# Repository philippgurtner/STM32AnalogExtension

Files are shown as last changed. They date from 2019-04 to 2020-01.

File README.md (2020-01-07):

# STM32AnalogExtension
In diesem Repository befinden sich die Daten für eine analog Erweiterung, bestehend aus einem externen ADC für das STM32F0-Discovery Board. 
Im weiteren ist die komplette Dokumentation, so dass die Projektschritte verstanden werden können und auch das Projekt verständlich wird. 

Das Projekt ist OpenSource & darf frei verwendet (und so auch gerne verbessert) werden. 
Ich hoffe viel Freude damit zu bereiten. 
:)

# Projektdokumentation

## Aufgabe
Für die Bereichsübergreifende Projekte der Schule sollte eine Erweiterung für das STM32F051Discovery Kit erstellt werden. 
Dieses Projekt ist eine Analoge Erweiterung mit einem 24Bit 4kSps externen ADC. Dabei ist wichtig dass die Erweiterung mit SPI Angesteuert wird. 
Mehr im Fokus des Projektes stand die Einfachheit, so das das Produkt einfach angewendet werden kann, als es Sehr genau ist. 
So wurde bei der Temperaturmessung auf die Konstantstromquelle Verzichtet, jedoch können zukünftige Anwender die tolle Auflösung mit allen Problemen und Hürden selbst erfahren. 

### Vorgaben
-	Es soll nur eine Seite für Anschlüsse genutzt werden
-	Die Erweiterungsplatine sitzt also zur rechten oder linken Seite des STM32F0-Board
-	Die Seite wird durch die Versorgungsspannung vorgegeben, wenn möglich 3V
-	Platinendicke 1,6mm
-	Lagenanzahl: 2
-	Bestückungsdruck: Schriftgrösse 1mm  Name der Bauteile, Stecker Pin 1, Signalnamen Stecker 
    - 2mm Name Projekt, Datum, Namen der Ersteller
-	Line Space ≥200μm
-	GND-Plane
-	Abmessung Discovery-Board: 33Pin Header

### Zielsetzung
- Das Board muss passend als Erweiterung für das Devboard sein, so dass es einfach adaptiert werden kann. 
- Die Hauptanwendung besteht darin einen 3-Leiter PT100 zu messen.
- Weiter soll möglich sein, durch eine Buchse eine eigene Messspannung hinzuzuführen, so dass auch diese digitalisiert werden kann. 
- Durch einen hochauflösenden ADC (>16Bit) werden dann hohe Genauigkeiten möglich.

## Grundlagen
### Analog-Digital-Converter (ADC)
Die Aufgabe eines ADC’s, ist die Umwandlung von analogen Signalen zu digitalen Daten. Dabei sind mehrere Faktoren wichtig, wie SampleRate und Auflösung (Bittiefe). Um die Signale zu ermitteln müssen wir wissen, was für eine Auflösung der ADC hat. Denn mit diesem, wissen wir wie fein wir das analoge Signal aufteilen können und so die digitalen Werte erhalten. Anhand der SampleRate sehen wir, wie viel Mal der ADC in der Sekunde das analoge Signal maximal abtasten kann. Mit diesen beiden Werten können wir dann in der Software die Werte in unser Signal umrechnen.
### Temperatursensorschaltungen

Um einen Temperatursensor anzuschliessen gibt es verschiedene Möglichkeiten. Diese sind für thermisch abhängige Widerstände, welche als Temperatursensoren funktionieren. Zum Beispiel PT100 oder PT1000. 

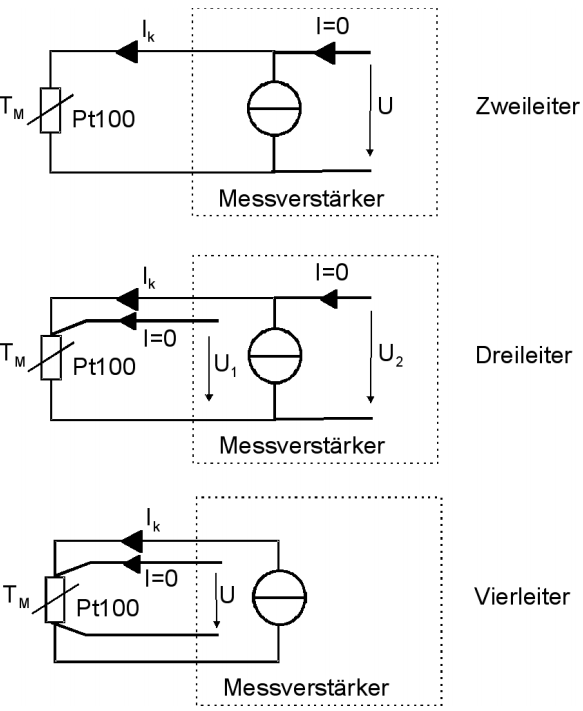
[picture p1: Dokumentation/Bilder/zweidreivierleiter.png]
Schaltung Zweileiter, Dreileiter, Vierleiter


#### Zweileiter-Messung
Der Messwiderstand (Temperatursensor) wird über dieselbe Leitung gespiesen wie auch die Temperatur gemessen wird. Daher, dass über die Leitungen ebenfalls etwas Spannung abfällt, wird dieser Fehler nicht mit einberechnet und wird zu einem Messfehler. 
#### Dreileiter- Messung
Bei der Dreileitermessung wird der Messwiderstand über eine zusätzliche Leitung mit Strom versorgt. Daher fällt einerseits der Messfehler der Spannung weg, da die Temperatur über eine unbelastete Leitung gemessen werden kann. Da der Strom I=0A auf der Messleitung ist kann auf der gemeinsamen Leitung der Messfehler herausgerechnet werden -> Siehe Anwendung. 
#### Vierleiter- Messung
Bei einer Vierleitermessung werden der Messstrom und die Messspannung je auf einer separaten Leitung geführt. So kann der Widerstand komplett ohne Spannungsabfall auf der Messleitung gemessen werden.

## Evaluation
###	ADC
Beim Evaluieren eines ADC’s gibt es sehr viele Möglichkeiten. Die wichtigsten Eigenschaften sind Auflösung (Bittiefe) und Geschwindigkeit (Samples per Second). 
Für dieses Projekt spielt die Geschwindigkeit keine grosse Rolle, da Prozesswerte abgefragt werden möchten und es sich nicht um eine Digitalisierung eines hochfrequenten Signals handelt. 
Die Auflösung spielt für dieses Projekt die grössere Rolle. Da gezeigt werden möchte wie genau der ADC ist, soll die Temperatur des Temperatursensors ohne jegliche Verstärkung gemessen werden. 
Die Berechnungen zu der Temperaturauflösung sind in Tabelle 1 zu finden. \todo

### Temperatursensor
Als Temperatursensor eignet sich ein thermisch abhängiger Widerstand sehr gut. Diese werden oft auch in Industrieanlagen verwendet. Da gerade ein fertiger PT100 Sensor an Lager ist wird dieser Verwendet, er benötigt nur eine Buchse auf der Platine um den Sensor anzuhängen. 
###	Weitere Anschlüsse
Als zusätzliche Anschlüsse wurden BNC Buchsen ausgewählt. Durch ihre Standardisierung und häufigen gebrauch eignen sie sich gut um weitere Signale anzulegen und zu messen. 
Es können dann entweder Oszilloskop-Messspitzen oder auch Adapter auf andere Hochfrequenz Stecker, wie auch auf Bananenbuchse verwendet werden. 

## Schaltungsaufbau
### 3-Leitermessung
Für diese Schaltung wird eine Dreileiter-Messung für den Temperatursensor verwendet, da diese sehr einfach aufzubauen, wie auch dann interessant zu verarbeiten ist. Weiter sind hier nur 3 ADC Kanäle nötig obwohl wie bei einer 4-Leiter Messung auch der Widerstand der Messleitung herausgerechnet werden kann.  
### ADC-Serial Interface
Der ADC besitzt ein Serial Peripherie Interface (SPI). Über diese kann mit dem Microcontroller kommuniziert werden. Damit die Peripherie nicht per Bit-Banging angesteuert werden muss, müssen die SPI-Anschlüsse beim Microcontroller an einen SPI fähigen Port geroutet werden.
### Funktion der Schaltung / Überlegungen
Dank folgender Rechnung wird ersichtlich wie die Spannung über dem PT100 berechnet werden kann. Dies funktioniert nach der theoretischen Betrachtung in Abbildung 4.
Es werden hier alle anderen Spannungen herausgerechnet. 

## Auswertung V0.1 
### Hardware
Während der Lötarbeit konnten wir nichts Auffälliges erkennen, was beim Löten problematisch werden könnte. Erst beim Konfigurieren der SPI-Schnittstelle mit der STM32CubeMX-Software, haben wir festgestellt, dass die SPI-Schnittstelle nicht frei auf alle Pins mapbar ist, wie wir das fälschlicherweise aus dem Datenblatt gelesen haben.
Somit müssen am Schema noch einige Anpassungen gemacht werden. Weiter haben wir auch während der Bearbeitung gemerkt, dass der ADC mit Differenzmessung arbeitet. Dies bedeutet, er misst die Differenz zwischen zwei Kanälen. Möchte man eine Spannung absolut messen, so muss dies mit einer Differenzmessung zu Masse erfolgen. Der Chip bietet die Möglichkeit im INPMUX-Register als negative Referenz den AINCOM-Pin zu verwenden, der aber mit Masse verbunden sein sollte.
Für die ersten Versuche mit dem Prototyp haben wir die Kontakte auf der Leiterplatte korrigiert, so dass wir Tests durchführen konnten. Als Erweiterung für die nächste Version wäre zusätzlich eine Stiftleiste vorzusehen, dass die SPI-Analyse einfacher mit einem Logicanalyzer erfolgen kann. Dies hat auch einen Vorteil für den späteren Unterricht, so kann die SPI-Schnittstelle einfacher analysiert werden. 

In der nachfolgenden Tabelle sind die Leiterplattenänderungen festgehalten:

| WAS | von | Nach | div. |
|---|---|---|---|
| Clock | PA4 | PA5 | SPI |
| MOSI | PA5 | PA7 | SPI |
| CS | PA7 | PF5 | SPI |
| AINCOM | Nc | GND | Differenzmessung |
| Stiftleiste | | | Für Debugging / SPI-Analyse |
| Widerstände R12-R14 | Eingang von ADC | weglassen | Können Störungen auf Messleitung verursachen |
| BNC-Abschwächer | 2.2k Ohm | Spannungsteiler mit 47kOhm und 2.2kOhm | Somit können Eingangsspannungen bis zu 50V angelegt werden und nicht nur 2.5V über die Interne Referenz |
| 5.08mm schraubklemme | Weglassen | | So können die Temperatursignale direkter und präziser geroutet werden. Der Stecker wird nicht benötigt. |
| Kondensatoren 1uF | AIN0, AIN1, AIN2 | GND | Filterung der Temp Messung |
| Kondensator 1uF | AIN0 | AIN1 | Filterung der Temp Messung | | |

## Softwarerealisierung 
### Konfiguration mit STM32CubeMX
Vorzunehmende Konfigurationen in STM32CubeMX, um die SPI-Schnittstelle zu verwenden: 
Beim Starten das STM32F0-Discovery Board auswählen, so werden die Taster und LEDs richtig initialisiert
-   Pinout & Konfiguration:
    - Pin-Konfiguration
        - PF5: 	ADC_CS
        - PC4: 	ADC_START
        - PC5: 	ADC_RESET
        - PB0: 	ADC_DRDY
    - Modul Connectivity --> SPI1 hinzufügen
        - Data Size: 	8Bit
        - Prescaler:
        - First Bit: 	MSB First
        - Clock Polarity (CPOL): 	LOW
        - Clock Phase (CPHA): 		2 Edge
- Project Manger
    - Code Generator
    - Generate Files: Generate peripheral initialization as a pair... 
        (So wird nicht eine lange main.c-Datei erzeugt)

### Verwenden von HAL-Library 
Hardware Abstraction Librarys, kurz HAL, dienen dazu unabhängig von der verwendeten Hardware, eine Software zu schreiben. So kann eine mit HAL geschriebene Software einfach auf ein anderes System portiert werden und das System übernimmt die Hardwaresteuerung, so dass der Nutzercode nicht (gross) angepasst werden muss. So wird zum Beispiel das Schreiben eines Pins ganz einfach, man muss sich nicht mehr überlegen wo der gerade angeschlossen ist, man benutzt einfach das Userlabel zum Pin. 
```c
HAL_GPIO_WritePin(ADC_CS_GPIO_Port, ADC_CS_Pin,X)
// X=1 --> Ausgang wird auf 1 gesetzt
// X=0 --> Ausgang wird auf 0 gesetzt
```

### SPI-Analyse mit Logicanalyzer

Erweiterungen siehe Anhang
In vielen Fällen kann es hilfreich sein, wenn man mit einem Busprotokoll arbeitet, dieses auch zu messen. Es stand uns dazu ein PicoScope6 zur Verfügung. Sie können bis zu 16 Digitalanalysen und 2 Analoganalysen machen. Es ist ein Oszilloskop ohne Bildschirm. In der Software (Für Windows, MacOS und Linux) kann man das PicoScope steuern. Folgend unsere Erfahrungen. 
Im Anhang befindet sich eine Anleitung wie man eine Analyse der SPI Daten machen kann.

## Softwarefunktionen
Einen kurzen Einblick in die Funktionen welche eingesetzt werden. Weitere Details können dem Code entnommen werden. 
### Registermanipulation
Zum Schreiben und lesen von Registern gibt es die Funktionen (Auszug .h File): 

\todo

Wenn nur ein Register gelesen / geschrieben werden muss, so kann jeweils die ADCreg**** Funktion benutzt werden
### Commands
Der ADC kann über verschiedene Kommandos gesteuert werden. Diese sind alle in der "ADS1204S0x.h" Datei definiert.
```c
void ADCsendCommand(uint8_t op_code);
```
Der Funktion können die Verschiedenen op_codes mitgegeben werden. 

### Berechnungsfunktionen
#### ADC Werte auslesen
Um die Spannung über dem PT100 zu berechnen, werden alle Spannungen der drei ADC`s ausgelesen. Wie hier dargestellt messen die ADC`s folgende Spannungen:

```math
\mathrm{ADC0}=U_{\mathrm{Leiter}}+U_{\mathrm{PT100}}+U_{\mathrm{Leiter}}+U_{\mathrm{Mess}}\bigm\mathrm{ADC1}=U_{\mathrm{Leiter}}+U_{\mathrm{Mess}}\bigm\mathrm{ADC2}=U_{\mathrm{Mess}}\bigmU_{\mathrm{PT100}}=\mathrm{ADC0}-2\times U_{\mathrm{Leiter}}-U_{\mathrm{Mess}}\bigmU_{\mathrm{PT100}}=\mathrm{ADC0}-2\times\left(\mathrm{ADC1}-\mathrm{ADC2}\right)-\mathrm{ADC2\bigm}U_{\mathrm{PT100}}=\mathrm{ADC0}-2\times\mathrm{ADC1}+\mathrm{ADC2}
```
### Dimensionierungen und Berechnungen
Als Temperatursensor wird ein PT100 verwendet. Nach Spezifikation hat der Temperatursensor bei 0°C einen 100Ω Widerstand. Je nach Temperatur verändert sich der Widerstand, nach einer bestimmten Kurve. 
Als Messstrom wird bei 0°C 0.5mA verwendet. Da sich der Temperatursensor selbst erwärmt darf dieser Messstrom nicht zu hoch gewählt werden.
Um den geflossenen Strom durch den ADC zu messen, wird über einem präzisen Referenzwiderstand die Spannung gemessen, welche vom Messstrom erzeugt wird.

Anschlüsse:
Es wurde eine Temperaturmessung mittels PT100 3-Leiter Widerstand vorgenommen. 
Als zusätzliche Anschlüsse wurden BNC Buchsen ausgewählt. Durch ihre Stndrdisierung und often gebrauch eignen sie sich um weitere Signale anzulegen und zu messen. 

# Schaltungsaufbau
## ADC-Serial Interface
Der ADC besitzt ein Serial Peripherie Interface (SPI). Über dies kann mit dem Microntroller Komunizieren. 
Damit die Peripherie nicht per Bit-Banging angesteuert werden muss, müssen sie beim Microcontroller mit bei einem SPI fähigen Port verbunden werden.
# Dimensionierung
Als Temperatursensor wird ein TP100 verwendet. Nach Spezifikation hat der Temperatursensor bei 0°C 100R Widerstand. Je nach Temperaturänderung verändert sich der Widerstand nach einer Spezifizierten Kurve. 
Als Messstrom wird bei 0°C 0.5mA verwendet. Da sich der Temperatursensor selbst erwärmt darf dieser Messstrom nicht zu hoch gewählt werden. 

Um den Geflossenen Strom durch den ADC zu messen wird über einem Refererenzwiderstand die Spannung gemessen welche vom Messstrom erzeugt wird. 

# Einführung Picoscope

Das Picoscope ist ein Logicanalyser. Mit ihm ist es Möglich mehrere Digitale Signale zu Analysieren und die Daten auszuwerten. Um Herauszufinden ob die Serielle Kommunikation richtig Funktioniert kann man mit diesem Hilfsmittel einfacher messen und die Daten analysieren. 

## Vorbereitung

Um Das Picoscope an einem PC benutzen zu können sind einige Schritte notwendig. 

### Installieren der Software

Die Software kann auf der Webseite von Picosope unter > Downloads heruntergeladen werden. 
Hier muss die Genaue Modelbezeichung angegeben werden. (Wir verwendeten das Picoscope der Schule [*PicoScope 2206B MSO*](https://www.picotech.com/downloads/_lightbox/picoscope-6))

### Anschliessen der Digitalen Kanäle

Die Digitalen Kanäle befinden sich beim 16-Pin Stecker in der Mitte. Das Mitgelieferte Kabel dient um mit dem UC Board zu verbinden. 

### Einrichten der Software

1. Digitale Kanäle Gruppen

   1. Kanal Auswählen

   2. Kanal intelligent benennen

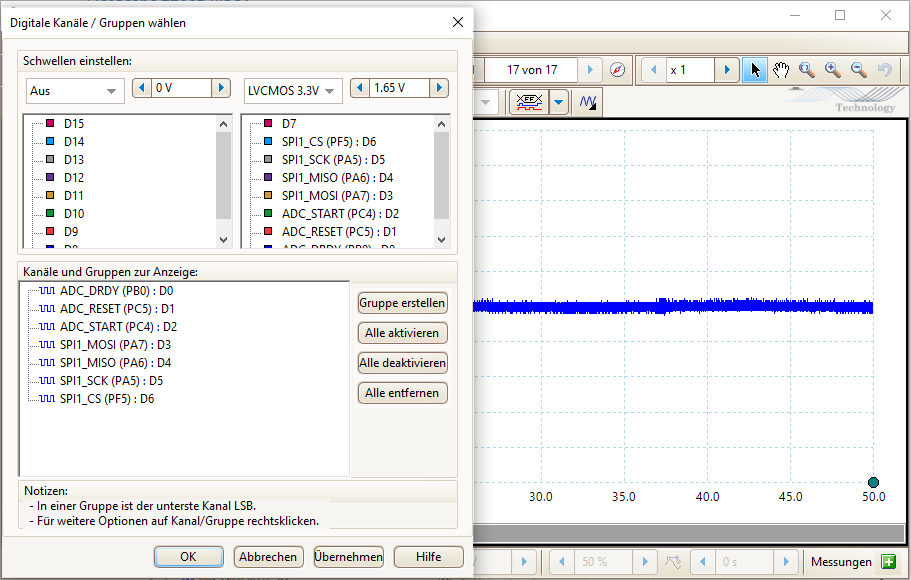
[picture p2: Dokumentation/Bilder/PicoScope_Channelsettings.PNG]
Digitale Kanäle
      

2. Hinzufügen eines Seriellen Encoders:

   1. Werkzeuge > Serielle Entschlüsselung -> Erstellen > SPI >

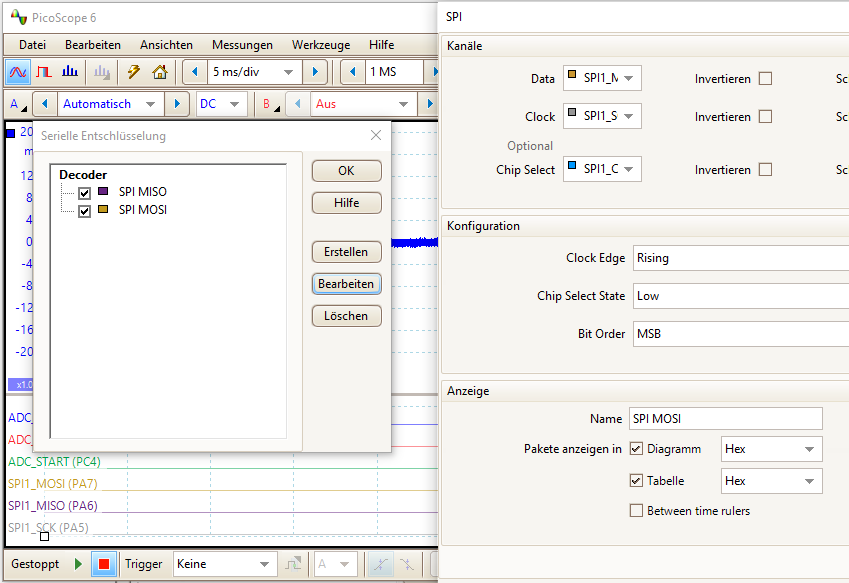
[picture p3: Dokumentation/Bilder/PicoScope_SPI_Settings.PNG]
SPI Analyser MISO and MOSI


3. Setzen des Triggers (In der untersten Leiste)
   1. Trigger: Einzeln
   2. In den Triggereinstellungen (Rechts vom Trigger) kann auf Digital > CS Pos Flanke gesetzt werden
   3. Start

## SPI Analyse

Mit den Empfangen Daten lässt sich verstehen was in SPI gesendet wird

Folgend im Code und Als Analyse:

MISO, Die Daten werden vom Master an den Slave gesendet. Die Rückgabe des Slaves ist nicht wichtig. 

```c
HAL_GPIO_WritePin(ADC_CS_GPIO_Port, ADC_CS_Pin,0);

uint8_t au8_txdata = {0x42,		// Register INPMUX_REG_ADDR (0x02) | Write command 0x40
                      0,		// Write length -1 = 0
                      0x3C};	// Data = ADS_P_AIN3 (0x30)+ ADS_N_AINCOM (0x0C)		
HAL_SPI_Transmit(&hspi1,au8_txdata,3,10);
HAL_GPIO_WritePin(ADC_CS_GPIO_Port, ADC_CS_Pin,1);
```

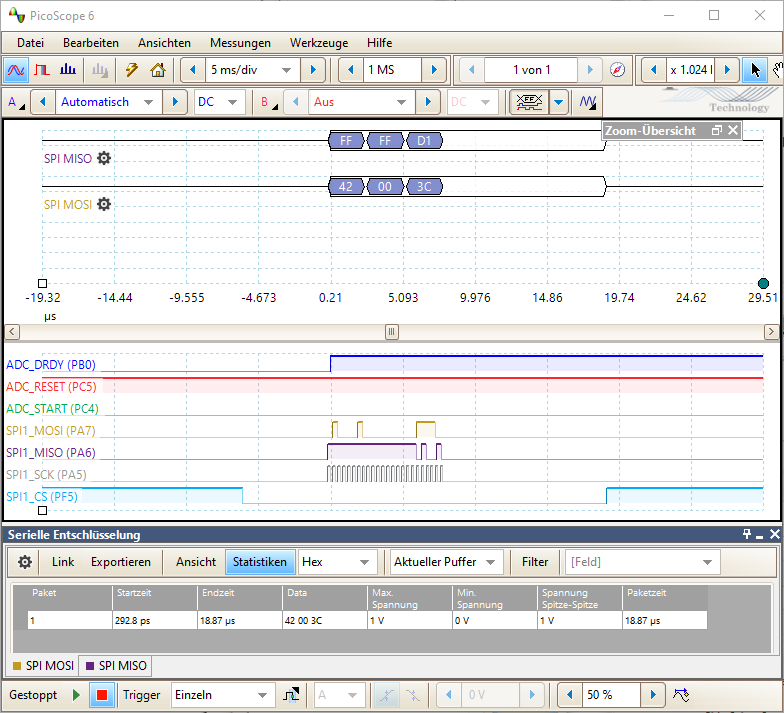
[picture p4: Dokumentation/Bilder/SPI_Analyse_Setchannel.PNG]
SPI Set Channel


# Variablen Viewer installieren (debuggen)

Das STMStudio ermöglicht es eine *debug Datei zu Importieren und diese Laufen zu lassen. So können mehrere globale Variablen angesehen werden. So kann eine Langzeitanalyse des Verhalten gemacht werden. 

- STM-STUDIO-STM32 (von https://www.st.com/en/development-tools/stm-studio-stm32.html ) installieren (benötigt Java https://www.java.com/de/download/win10.jsp)

- STM Studio öffnen

- "File" > "Import variables from executable" öffnen
  - "Executable file" .elf Datei suchen (im STM Projekt unter "Debugger")
  - (Warnung Ignorieren)
  - Variable zum Monitoren auswählen 
  - "Import" , "Close"

- Variable (Display Variables) in Viewer hineinziehen (Drag and Drop)

- Start Knopf drücken (Debugger aus IDE darf nicht gleichzeitig aktiv sein)

- Im Viewer: Rechtsklick, "Autorange" > "Both Axis"

- Eventuell als Balken darstellen, maximum wert beachten (über hex ganz einfach manuell einstellbar)

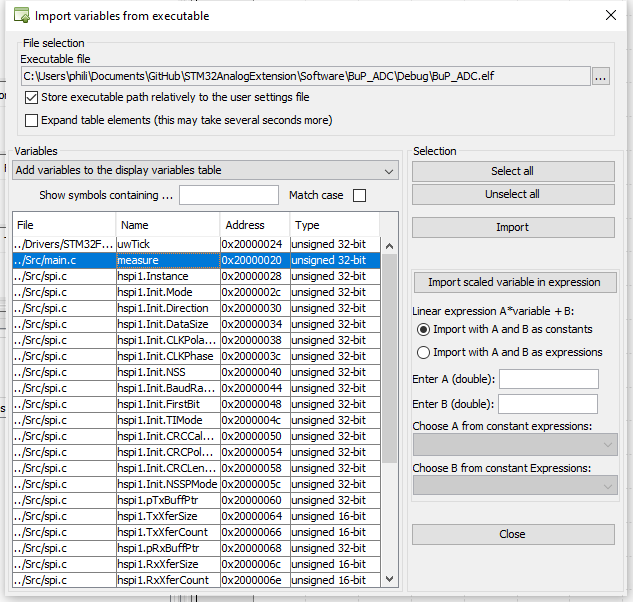
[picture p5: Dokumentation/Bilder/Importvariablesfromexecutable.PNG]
Import variables


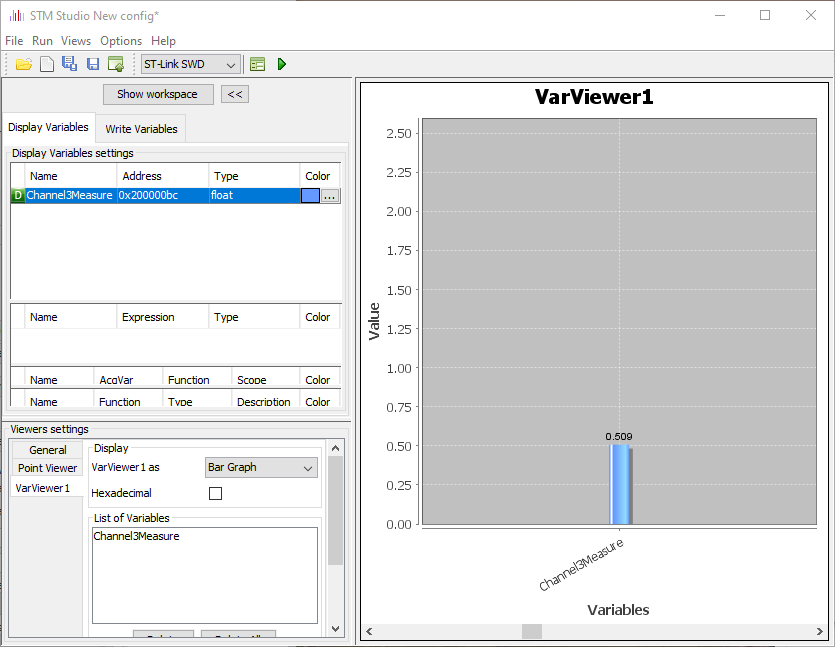
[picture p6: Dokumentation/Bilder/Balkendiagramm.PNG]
Variablenviewer als Balkenanzeige


# Sorry, die vollständige Dokumentation ist Leider nicht Opensource (und vorallem .docx), jedoch wird das Projekt bei Gelegenheit hier noch zu ende Dokumentiert (natürlich in MD :) , Danke für die Geduld)

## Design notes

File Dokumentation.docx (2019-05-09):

Noëmi Kurt & Philipp Gurtner

ADC-BOARD

STM23F0-board

# 1 Abbildungsverzeichnis

# 2 Projektdaten

Projektleiter: Noëmi Kurt & Philipp Gurtner

Stellvertretender Projektleiter: -

Verantwortlicher Auftragsgeber (mit Abteilung): Ronny Bachmann

Stellvertretende Ansprechperson des Auftragsgebers: -

Projektname / Bezeichnung: ADC-Board

Kostenstelle / Projektnummer.: -

Annahmedatum: 28.02.2019

Abgeschlossen am: [Veröffentlichungsdatum]

# 3 Aufgabe

Im berufsübergreifenden Projekt-Unterricht haben wir den Auftrag erhalten, ein neues Board für das erste und zweite Lehrjahr entwickeln zu helfen, da die Schule die Silicon Labs C8051 FX20-Boarde nicht mehr verwenden möchte. Jetzt ist das Ziel mit dem STM32F0-Discovery-Board verschiedene Zusatzboards zu entwickeln.

Unsere Aufgabe ist es nun ein ADC mit dem Board zu verknüpfen und ein Programm zu schreiben, welches mit dem ADC per SPI kommuniziert und die Spannungsmessung ausgibt.

## 3.1 Vorgaben

- Es soll nur eine Seite für Anschlüsse genutzt werden
- Die Erweiterungsplatine sitzt also zur rechten oder linken Seite des STM32F0-Board
- Die Seite wird durch die Versorgungsspannung vorgegeben, wenn möglich 3V
- Platinendicke 1,6mm
- Lagenanzahl: 2
- Bestückungsdruck: Schriftgrösse 1mm → Name der Bauteile, Stecker Pin 1, Signalnamen Stecker
  - 2mm Name Projekt, Datum, Namen der Ersteller
- Line Space ≥200μm

Abbildung 1 Abmessungen vom Discovery-Board

- GND-Plane
- Abmessung Discovery-Board: 33Pin Header

# 4 Grundlagen

## 4.1 Analog-Digital-Converter (ADC)

Das Aufgabe eines ADC’s, ist die Umwandlung von analogen Signalen zu digitalen Daten. Dabei sind mehrere Faktoren wichtig, wie SampleRate und Auflösung(Bittiefe). Um die Signale zu ermitteln müssen wir wissen, was für eine Auflösung der ADC hat. Denn mit diesem, wissen wir wie fein wir das analoge Signal aufteilen können und so die digitalen Werte erhalten. Anhand der SampleRate sehen wir, wie viel Mal der ADC in der Sekunde das analoge Signal maximal abtasten kann. Mit diesen beiden Werten können wir dann in der Software die Werte in unser Signal umrechnen.

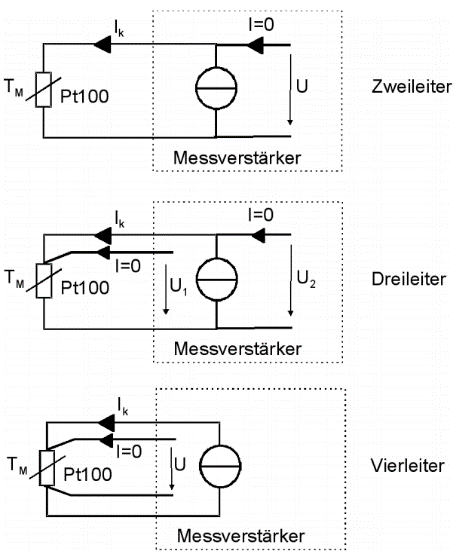
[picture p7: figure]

## 4.2 Temperatursensorschaltungen

Abbildung 3 Anschluss von Widerstandsthermometern

Um einen Temperatursensor anzuschliessen gibt es verschiedene Möglichkeiten. Diese sind für thermisch abhängige Widerstände, welche als Temperatursensoren funktionieren. Zum Beispiel PT100 oder PT1000)

Zweileiter-Messung
Der Messwiderstand (Temperatursensor) wird über die Selbe Leitung gespiesen wie auch die Temperatur gemessen wird. Daher, dass über die Leitungen ebenfalls etwas Spannung abfällt, wird dieser Fehler nicht mit einberechnet und wird zu einem Messfehler.

Dreileiter- Messung
Bei der Dreileitermessung wird der Messwiderstand über eine zusätzliche Leitung mit Strom versorgt. Daher fällt einerseits der Messfehler der Spannung weg, da die Temperatur über eine unbelastete Leitung gemessen werden kann. Da der Strom I=0A auf der Messleitung ist kann auf der gemeinsamen Leitung der Messfehler herausgerechnet werden -> Siehe Anwendung.

Vierleiter- Messung
Bei einer Vierleitermessung werden der Messstrom und die Messspannung je auf einer seperaten Leitung geführt. So kann der Widerstand komplett ohne Spannungsabfall auf der Messleitung gemessen werden.

# 5 Planung

## 5.1 Zielsetzung

- Das Board muss passend als Erweiterung für das Devboard sein, so dass es einfach adaptiert werden kann.
- Die Hauptanwendung besteht darin einen 3-Leiter PT100 zu messen.
- Weiter soll möglich sein, durch eine Buchse eine eigene Messspannung hinzuzuführen, so dass auch diese digitalisiert werden kann.
- Durch einen hochauflösenden ADC (>16Bit) werden dann hohe Genauigkeiten möglich.

## 5.2 Zeitplan

✓Evaluieren ADC | .5h
✓Evaluieren rest. Teile | 1h
✓Schemadesign | 2h
✓Layout | 2h
Dokumentation | 6h
Software Library | 8h
Assembly Prototype | 1h
| 20.5h

## 5.3 Meilensteine

28.02.19 | Abgabe Pflichtenheft
11.04.19 | Zwischenbricht
06.06.19 | Präsentation

# 6 Ausführung

Abbildung 2 Blockschaltbild ADC-Board

SPI

ADC

PT100

Connector
BNC

uC

Nach dem Schaltungskonzept Abbildung 2 werden die Bauteile evaluiert.

## 6.1 Evaluation

### 6.1.1 ADC

Beim Evaluieren eines ADC’s gibt es sehr viele Möglichkeiten. Die wichtigsten Eigenschaften sind Auflösung (Bittiefe) und Geschwindigkeit (Samples per Second).
Für dieses Projekt spielt die Geschwindigkeit keine grosse Rolle, da Prozesswerte abgefragt werden möchten und es sich nicht um eine Digitalisierung eines hochfrequenten Signals handelt.
Die Auflösung spielt für dieses Projekt die grössere Rolle. Da gezeigt werden möchte wie genau der ADC ist soll die Temperatur des Temperatursensors ohne jegliche Verstärkung gemessen werden.
Die Berechnungen zu der Temperaturauflösung sind in Tabelle 1 zu finden.

### 6.1.2 Temperatursensor

Als Temperatursensor eignet sich ein thermisch abhängiger Widerstand sehr gut. Diese werden oft auch in Industrieanlagen verwendet. Da gerade ein fertiger PT100 Sensor an Lager ist wird dieser Verwendet, er benötigt nur eine Buchse auf der Platine um den Sensor anzuhängen.

### 6.1.3 Weitere Anschlüsse

Als zusätzliche Anschlüsse wurden BNC Buchsen ausgewählt. Durch ihre Standardisierung und häufigen gebrauch eignen sie sich gut um weitere Signale anzulegen und zu messen.
Es können dann entweder Oszilloskop-Messspitzen oder auch Adapter auf andere Hochfrequenz Stecker, wie auch auf Bananenbuchse verwendet werden.

## 6.2 Schaltungsaufbau

### 6.2.1 3-Leitermessung

Für diese Schaltung wird eine Dreileiter-Messung für den Temperatursensor verwendet, da diese sehr einfach aufzubauen, wie auch dann interessant zu verarbeiten ist. Weiter sind hier wenige ADC Kanäle nötig.

### 6.2.2 ADC-Serial Interface

Der ADC besitzt ein Serial Peripherie Interface (SPI). Über dieses kann mit dem Microcontroller Kommunizieren. Damit die Peripherie nicht per Bit-Banging angesteuert werden muss, müssen die SPI Anschlüsse beim Microcontroller an einen SPI fähigen Port geroutet werden.

## 6.3 Funktion der Schaltung / Überlegungen

ADC1=U_(Leiter) +U_(PT100) +U_(Leiter) +U_(Mess) ADC2=U_(Leiter) +U_(Mess) ADC3=U_(Mess) U_(PT100) =ADC1-2*U_(Leiter) -U_(Mess) U_(PT100) =ADC1-2*(ADC2-ADC3)-ADC3

Dank dieser Rechnung wird ersichtlich wie die Spannung über dem PT100 berechnet werden kann.
Es wird hier alle anderen Spannungen herausgerechnet.

## 6.4 Dimensionierungen und Berechnungen

Als Temperatursensor wird ein TP100 verwendet. Nach Spezifikation hat der Temperatursensor bei 0°C 100Ω Widerstand. Je nach Temperatur verändert sich der Widerstand nach einer spezifizierten Kurve.
Als Messstrom wird bei 0°C 0.5mA verwendet. Da sich der Temperatursensor selbst erwärmt darf dieser Messstrom nicht zu hoch gewählt werden.

Um den geflossenen Strom durch den ADC zu messen wird über einem Refererenzwiderstand die Spannung gemessen welche vom Messstrom erzeugt wird.

### 6.4.1 Widerstände für 3-Leitermessung

Als Pullupwiderstand für die Messschaltung (R10) verwenden wir einen 2.2kΩ Widerstand. Dieser hat die Aufgabe den Messstrom zu begrenzen (Auf 0.5mA)

FORMEL

https://www.digikey.ch/product-detail/de/susumu/RG2012L-222-L-T05/408-1635-1-ND/3737819

Für den präzisionswiderstand haben wir uns entgegengesetzt der Vorgaben für einen 0805 Widerstand entschieden, da der Widerstand präzise und mit wenig ppm ausgestattet sein soll. Mit der 0603 Variante wäre der Preis ins All hinausgeschossen, was nicht unser Ziel ist. Damit wir aber trotzdem einen guten Wert erhalten konnten haben wir uns auf die besagte 0805 Variante geeinigt. Die Toleranz liegt somit bei 0.01% und bei 2ppm/°C.

https://www.digikey.com/product-detail/en/panasonic-electronic-components/ERA-3AEB3741V/P3.74KDBCT-ND/3075947

Für den Pullup Widerstand haben wir einen 3.74k Ohm Widerstand genommen. Über dem PT100 fällt bei

# 7 Anhang

## 7.1 Kalkulation ADC Auflösung

Tabelle 1 Kalkulation ADC Auflösung

R | 100Ω
I | 500.0E-6A
Temperatur | Faktor (Datenblatt) | U
-50°C | 0.803 | 40.2E-3V
50°C | 1.194 | 59.7E-3V
100°C | 1.385 | 69.3E-3V
150°C | 1.573 | 78.7E-3V
ΔU | 38.5E-3V | ΔU=U_(max) -U_(min)
ADC Auflösung | 16777216
VCC | 3.3E+0V
ADC Auflösung [V] | 196.7E-9V | Auflösung=(VCC)/(Auflösung)
Temp. Auflösung | 195734.1867 | Temp.Auflösung=(ΔU)/(ADC Auflösung) Temp.Auflösung=(ΔTEMP)/(ADC Auflösung)
Temp. Auflösung | 1.0E-3°C

Philipp Gurtner, Noëmi Kurt 11.04.2019 V0.2 1/2

ADC-Board

Bereichsübergreifendes Projekt

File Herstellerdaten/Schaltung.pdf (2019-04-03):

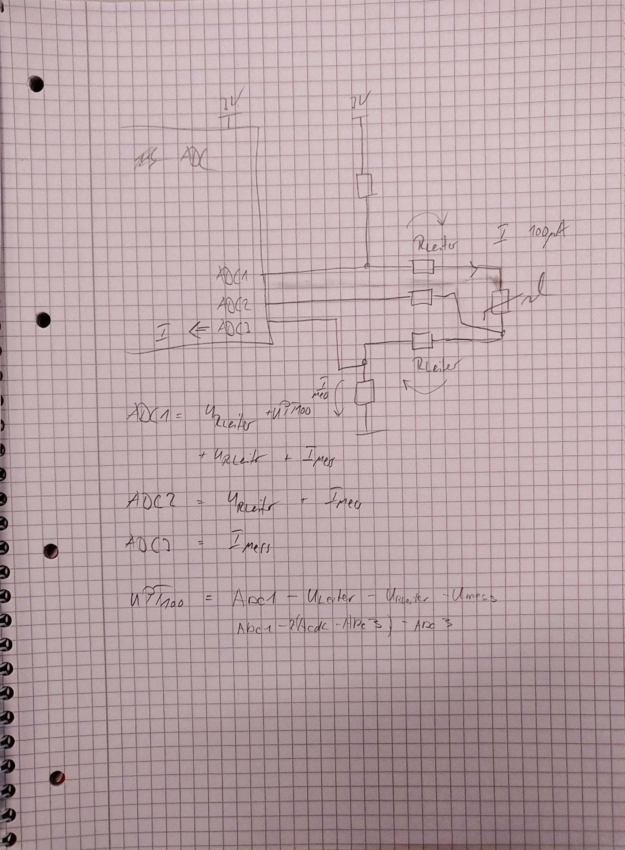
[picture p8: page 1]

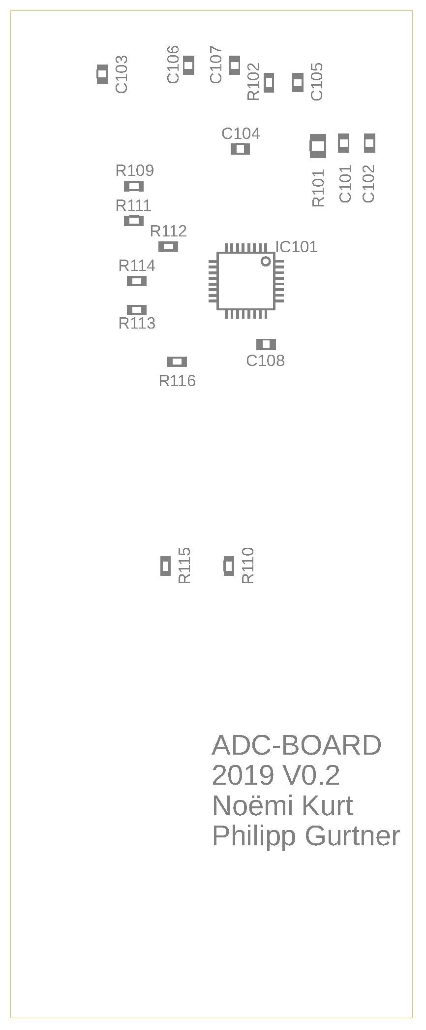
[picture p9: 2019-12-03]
Hardware/V02/Bilder/BOT_Assaembly.png

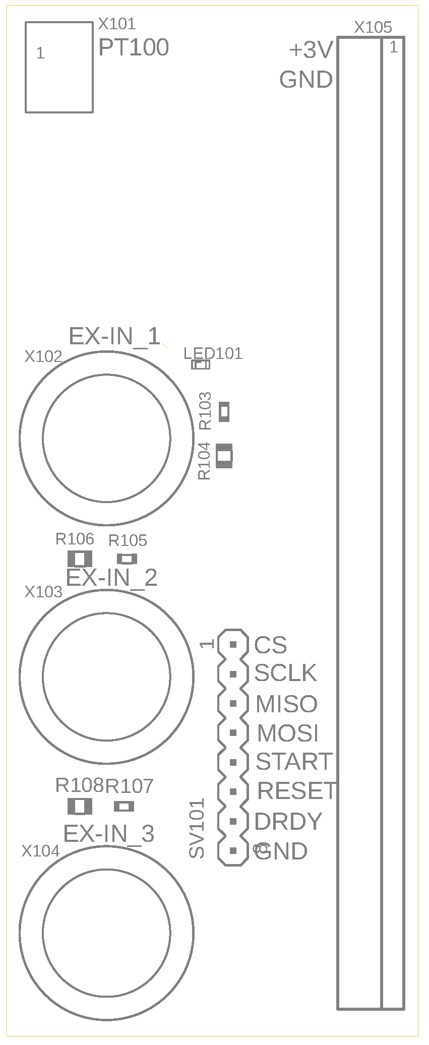
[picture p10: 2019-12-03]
Hardware/V02/Bilder/TOP_Assaembly.png

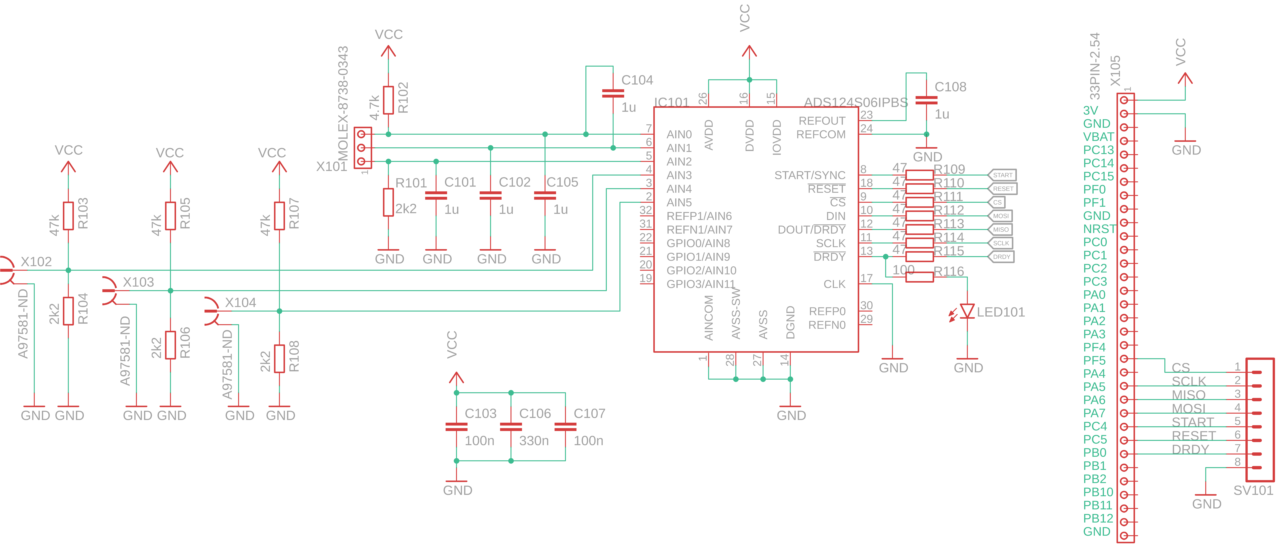
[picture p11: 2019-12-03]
Hardware/V02/Bilder/Schema.png

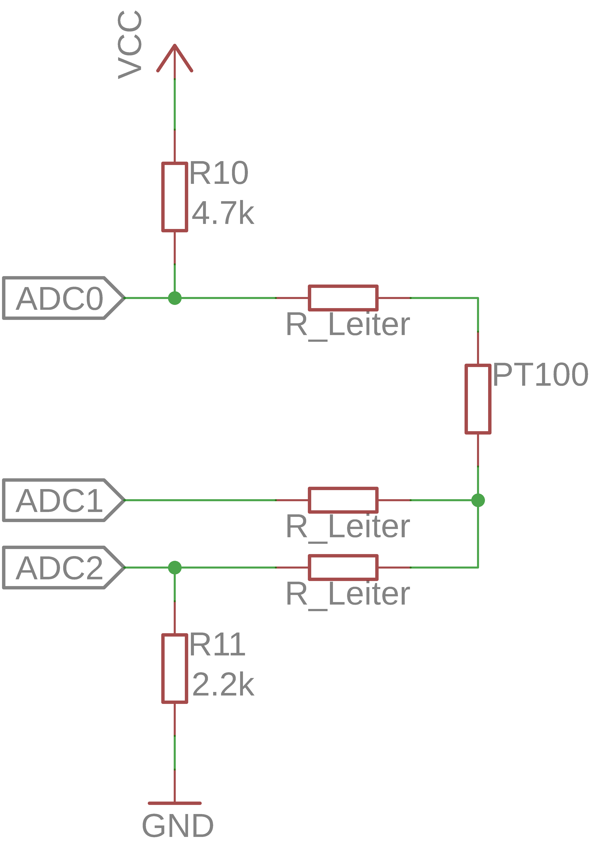
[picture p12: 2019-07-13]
Dokumentation/Bilder/PT100_schaltung.png

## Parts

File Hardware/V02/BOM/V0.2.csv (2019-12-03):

Qty | Value | Device | Package | Parts | Description | DIGIKEY_NR | DIGIKEY_PRICE
1 |  | LEDSML0603 | SML0603 | LED101 | LED | 475-3118-1-ND | 0.52
1 |  | MA08-1 | MA08-1 | SV101 | PIN HEADER | 732-5321-ND | 0.37
1 | 100 | R-EU_R0603 | R0603 | R116 | RESISTOR, European symbol | 311-100DCT-ND | 0.2
1 | 100n | C-EUC0603 | C0603 | C107 | CAPACITOR, European symbol | 1276-6439-1-ND | 0.1
1 | 100n | C-EUC0603 | C0603 | C103 | CAPACITOR, European symbol | 1276-6439-1-ND | 0.1
5 | 1u | C-EUC0603 | C0603 | C101, C102, C104, C105, C108 | CAPACITOR, European symbol | 1276-1182-1-ND | 0.1
4 | 2k2 | R-EU_R0805W | R0805W | R101, R104, R106, R108 | RESISTOR, European symbol | 408-1635-1-ND | 4.37
1 | 330n | C-EUC0603 | C0603 | C106 | CAPACITOR, European symbol | 490-6050-1-ND | 0.22
1 | 33PIN-2.54 | 33PIN-2.54 | 1X33 | X105 |  | 609-2223-ND | 1.41
1 | 4.7k | R-EU_R0603 | R0603 | R102 | RESISTOR, European symbol | 311-4.70KHRCT-ND | 0.1
7 | 47 | R-EU_R0603 | R0603 | R109, R110, R111, R112, R113, R114, R115 | RESISTOR, European symbol | 311-470GRCT-ND | 0.1
3 | 47k | R-EU_R0603 | R0603 | R103, R105, R107 | RESISTOR, European symbol | P123333CT-ND | 0.1
3 | A97581-ND | A97581-ND | 1634503 | X102, X103, X104 |  | A97581-ND | 1.73
1 | ADS124S06IPBS | ADS124S0XIPBS | TQFP32-05 | IC101 |  | 296-45188-ND | 10.15
1 | MOLEX-8738-0343 | MOLEX-8738-0343 | MOLEX-87438-0343 | X101 |  | WM7647CT-ND | 0.81

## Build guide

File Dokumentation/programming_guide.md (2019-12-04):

# Programmierguide
Als IDE wird die Opensoure-Freeware von STM verwendet. Sie kann unter ............... heruntergeladen werden. 
Die IDE beinhaltet folende module:

- STM32CubeMX	(Zum Konfigurieren der Hardware)
- Atollic Studio (Texteditor)
- ACR6 Debugger ???

## Konfiguration

Um das ADCBoard in ein Projekt einzubinden muss, bei einem STM32F0Discovery, folgende Konfigurationen gemacht werden. 

- Das Board kann beim erstellen des neuen STM32CubeMX Projekt ausgewählt werden

- Pinout & Configuration
	- Pinkonfiguration (Wichtig! Die User labels müssen genau gleich benannt werden --> HAL Namen wurden in Library übernommen)
		- PF5: ADC_CS
		- PC4: ADC_START
		- PC5: ADC_RESET
		- PB0: ADC_DRDY
	- Modul Connectivity>SPI1 hinzufügen
		- Data Size: 8Bit
		- First Bit: MSB First
		- Clock Polarity (CPOL): LOW
		- Clock Phase (CPHA): 2 Edge
- Project Manger
	- Code Generator
		- Generate Files: Generate peripheral initialization as a pair... (Erzeugt für jedes Modul eine eigene Datei. So Wird die main.c übersichtlicher)

Über das Zahnrad Symbol (Device Confiuration Tool Code Generation) kann der C-Code generiert werden. 

Beim weiteren Programmieren ist es wichtig sich an die vorgegebenen Schranken für Code zu halten. So kann noch immer eine neue Version generiert werden, ohne das handgeschriebener Code verlohren geht. 

## Programmablaf (nach [S.90](../Herstellerdaten/ads124s06.pdf#page=90) Datenblatt)

Als erstes muss der ADC Initialisiert werden. Dies geschieht über folgende komandos. Auf [Seite 90](../Herstellerdaten/ads124s06.pdf#page=90) des Datenblatts ist ein Pseudocode Beispiel zu finden, dieses wird hier Ebenfalls, wenn auch nicht gleich Detailliert behandelt. 

### Schleife

- Warten bis !DRDY 0 ist, also ADC fertig konvertiert hat. Dazu gibt es folgende Möglichkeiten
  - Pullen des Pins
  - Besser, über einen Interrupt der Ausgelöst wird wenn der Pin eine Negative Flanke hat. 
- ADC Adressieren, !CS = 0 
- Mindestens td(CSSC) Warten, dass ADC Bereit ist zu komunizieren. 
- Daten-lese-Komando senden, RDATA
- Empfangen von 24Bit, somit 24 Positive Flanken an SCLK ausgeben
- Mindestens td(SCCS) warten
- Serielles Interface zurücksetzen, !CS = 1

#### Code Beispiel

#### Prgrammieridee

Single read mode: daten werden nur dann gelesen wenn dies vom UC per start befehl geforderd wird, so kann auch jedes mal INPMUX neu gesetzt werden, dann gestartet werden. Sonst liest adc immer Kontinuierlich daten, auf dem gesetzten Kanal...

# Philipp Notizen zur Programmierstruktur
## Temperatur lesen // nicht ganz schön wegen langer ISR, dafür einfach anwendbar #KISS 
- Flag new temperature value = 0
- Setzen von Input auf AIN0
- ISR (Data Ready) 
	- Daten lesen Per command oder direkt (ehnter direkt da schon in der ISR)
	- Daten in variable (array) speichern

wenn noch nicht alle gelesen, dann:  
- Nächster input setzen (AIN1)

- if temperature value == 0 && alle daten gelesen 	
	auswerten der daten, flag setzen

3 Funktionen für die temperatur --> Buffern??

- if(newtemperature available)
	gettempperature();
- read temperature ---> muss in main immer ausfüren

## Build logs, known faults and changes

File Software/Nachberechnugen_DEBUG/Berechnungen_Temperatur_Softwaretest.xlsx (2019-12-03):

RawData
3259185 | ADC0 | 0.9713128209
3108612 | ADC1 | 0.92643857
3105986 | ADC2 | 0.925655961 |  | -0.0007826089859
Fullscale Voltage | 2.5 |  | 8388608
ADCsteps= | 147947
ADC_Voltage= | 0.02204582095 |  |  |  | 0.00034
Voltage R11 | 0.4628279805 |  |  |  | 0.0003978873577
Curent R11 | 0.0002103763548 |  | 3.720042524
x | 104.7922946
Simulation mit 120R
0.99151
0.94018
0.940144 | -3.6e-05
 | 427.3381818

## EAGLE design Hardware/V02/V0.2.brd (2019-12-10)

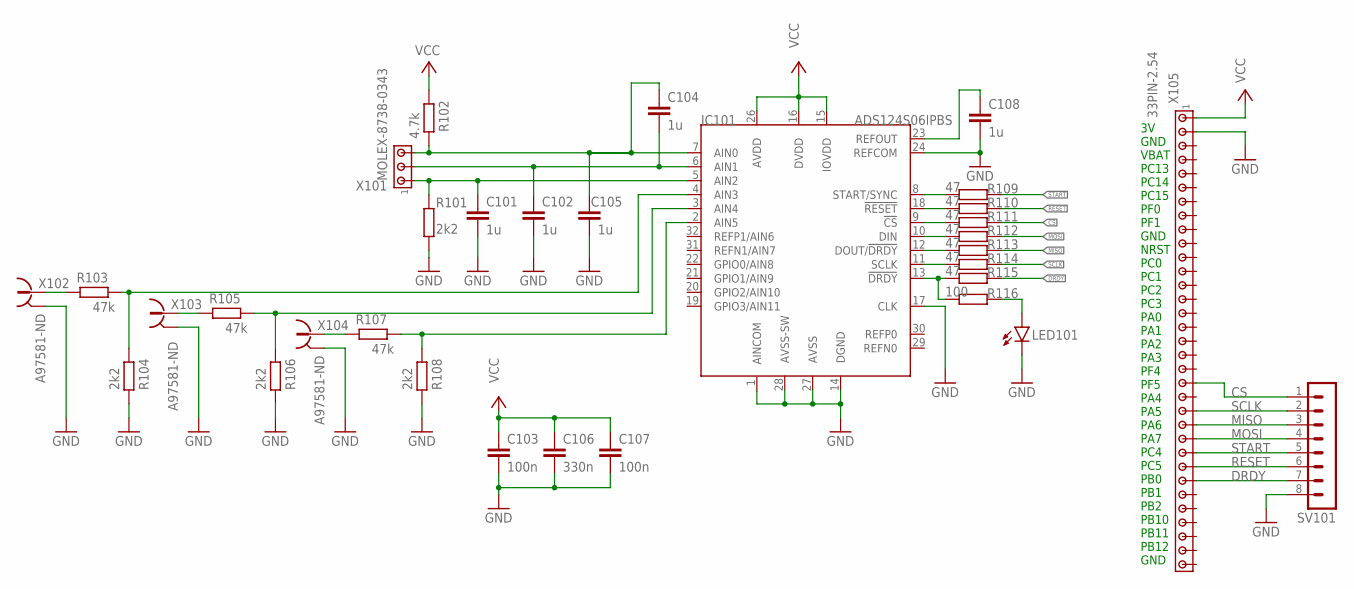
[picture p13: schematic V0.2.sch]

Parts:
C101, C102, C104, C105, C108: 1u; C0603; DIGIKEY_NR 1276-1182-1-ND
C103, C107: 100n; C0603; DIGIKEY_NR 1276-6439-1-ND
C106: 330n; C0603; DIGIKEY_NR 490-6050-1-ND
IC101: ADS124S06IPBS; TQFP32-05; DIGIKEY_NR 296-45188-ND
LED101: LEDSML0603; SML0603; DIGIKEY_NR 475-3118-1-ND
R101, R104, R106, R108: 2k2; R0805W; DIGIKEY_NR 408-1635-1-ND
R102: 4.7k; R0603; DIGIKEY_NR 311-4.70KHRCT-ND
R103, R105, R107: 47k; R0603; DIGIKEY_NR P123333CT-ND
R109, R110, R111, R112, R113, R114, R115: 47; R0603; DIGIKEY_NR 311-470GRCT-ND
R116: 100; R0603; DIGIKEY_NR 311-100DCT-ND
SV101: MA08-1; DIGIKEY_NR 732-5321-ND
X101: MOLEX-8738-0343; MOLEX-87438-0343; DIGIKEY_NR WM7647CT-ND
X102, X103, X104: A97581-ND; 1634503; DIGIKEY_NR A97581-ND
X105: 33PIN-2.54; 1X33; DIGIKEY_NR 609-2223-ND

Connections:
AIN0: C104.1, C105.1, IC101.7 (AIN0), R102.1, X101.3, X101.3_1 (3)
AIN1: C102.1, C104.2, IC101.6 (AIN1), X101.2, X101.2_1 (2)
AIN2: C101.1, IC101.5 (AIN2), R101.2, X101.1, X101.1_1 (1)
CS: R111.2, SV101.1, X105.20
DRDY: R115.2, SV101.7, X105.27
GND: C101.2, C102.2, C103.2, C105.2, C106.2, C107.2, C108.2, IC101.1 (AINCOM), IC101.14 (DGND), IC101.17 (CLK), IC101.24 (REFCOM), IC101.27 (AVSS), IC101.28 (AVSS-SW), LED101.C, R101.1, R104.1, R106.1, R108.1, SV101.8, X102.2, X102.3 (2), X102.4 (2), X102.5 (2), X103.2, X103.3 (2), X103.4 (2), X103.5 (2), X104.2, X104.3 (2), X104.4 (2), X104.5 (2), X105.2
MISO: R113.2, SV101.3, X105.23
MOSI: R112.2, SV101.4, X105.24
unnamed: IC101.8 (START/SYNC), R109.1
unnamed: IC101.18 (!RESET), R110.1
unnamed: IC101.9 (!CS), R111.1
unnamed: IC101.10 (DIN), R112.1
unnamed: IC101.12 (DOUT/!DRDY), R113.1
unnamed: IC101.11 (SCLK), R114.1
unnamed: IC101.13 (!DRDY), R115.1, R116.1
unnamed: IC101.4 (AIN3), R103.1, R104.2
unnamed: R103.2, X102.1
unnamed: R105.2, X103.1
unnamed: LED101.A, R116.2
unnamed: C108.1, IC101.23 (REFOUT)
unnamed: R107.2, X104.1
unnamed: IC101.3 (AIN4), R105.1, R106.2
unnamed: IC101.2 (AIN5), R107.1, R108.2
RESET: R110.2, SV101.6, X105.26
SCLK: R114.2, SV101.2, X105.22
START: R109.2, SV101.5, X105.25
VCC: C103.1, C106.1, C107.1, IC101.15 (IOVDD), IC101.16 (DVDD), IC101.26 (AVDD), R102.2, X105.1

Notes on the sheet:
3V GND VBAT PC13 PC14 PC15 PF0 PF1 GND NRST PC0 PC1 PC2 PC3 PA0 PA1 PA2 PA3 PF4 PF5 PA4 PA5 PA6 PA7 PC4 PC5 PB0 PB1 PB2 PB10 PB11 PB12 GND

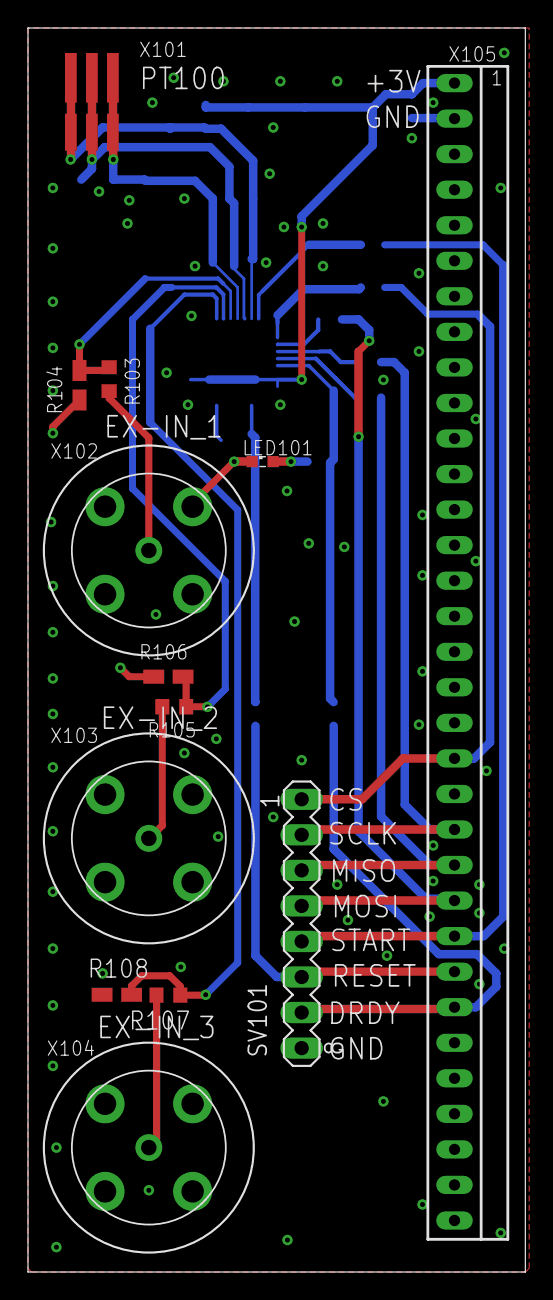
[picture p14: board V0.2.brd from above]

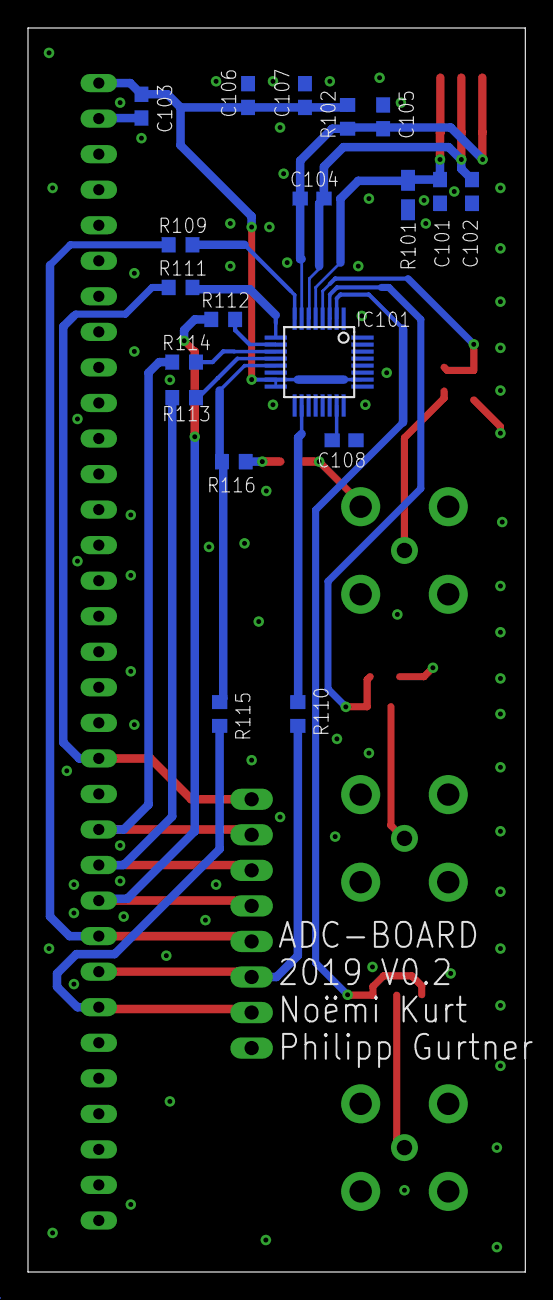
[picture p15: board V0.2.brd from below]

Board: 2 copper layers, 35.5 x 88.9 mm, 32 parts (19 on the bottom side), 27 nets.

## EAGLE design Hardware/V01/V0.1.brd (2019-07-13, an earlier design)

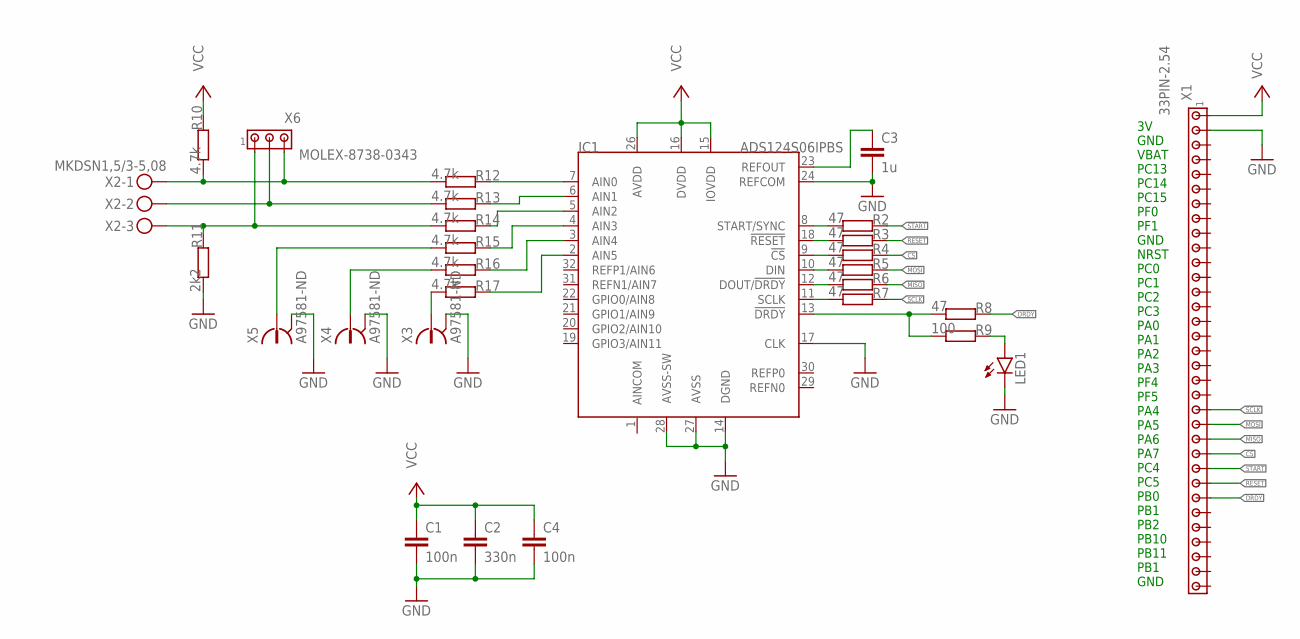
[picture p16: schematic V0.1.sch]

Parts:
C1, C4: 100n; C0603; DIGIKEY_NR 1276-6439-1-ND
C2: 330n; C0603; DIGIKEY_NR 490-6050-1-ND
C3: 1u; C0603; DIGIKEY_NR 1276-1182-1-ND
IC1: ADS124S06IPBS; TQFP32-05; DIGIKEY_NR 296-45188-ND
LED1: LEDSML0603; SML0603; DIGIKEY_NR 475-3118-1-ND
R2, R3, R4, R5, R6, R7, R8: 47; R0603; DIGIKEY_NR 311-470GRCT-ND
R9: 100; R0603; DIGIKEY_NR 311-100DCT-ND
R10, R12, R13, R14, R15, R16, R17: 4.7k; R0603; DIGIKEY_NR 311-4.70KHRCT-ND
R11: 2k2; R0805W; DIGIKEY_NR 408-1635-1-ND
X1: 33PIN-2.54; 1X33; DIGIKEY_NR 609-2223-ND
X2: MKDSN1,5/3-5,08; DIGIKEY_NR 277-14503-ND
X3, X4, X5: A97581-ND; 1634503; DIGIKEY_NR A97581-ND
X6: MOLEX-8738-0343; MOLEX-87438-0343; DIGIKEY_NR WM7647CT-ND

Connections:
CS: R4.2, X1.24
DRDY: R8.2, X1.27
GND: C1.2, C2.2, C3.2, C4.2, IC1.14 (DGND), IC1.17 (CLK), IC1.24 (REFCOM), IC1.27 (AVSS), IC1.28 (AVSS-SW), LED1.C, R11.1, X1.2, X3.2, X3.3 (2), X3.4 (2), X3.5 (2), X4.2, X4.3 (2), X4.4 (2), X4.5 (2), X5.2, X5.3 (2), X5.4 (2), X5.5 (2)
MISO: R6.2, X1.23
MOSI: R5.2, X1.22
unnamed: IC1.8 (START/SYNC), R2.1
unnamed: IC1.18 (!RESET), R3.1
unnamed: IC1.9 (!CS), R4.1
unnamed: IC1.10 (DIN), R5.1
unnamed: IC1.12 (DOUT/!DRDY), R6.1
unnamed: IC1.11 (SCLK), R7.1
unnamed: IC1.13 (!DRDY), R8.1, R9.1
unnamed: R10.1, R12.1, X2.1, X6.3, X6.3_1 (3)
unnamed: R13.1, X2.2, X6.2, X6.2_1 (2)
unnamed: R11.2, R14.1, X2.3, X6.1, X6.1_1 (1)
unnamed: R15.1, X5.1
unnamed: IC1.3 (AIN4), R16.2
unnamed: IC1.2 (AIN5), R17.2
unnamed: LED1.A, R9.2
unnamed: C3.1, IC1.23 (REFOUT)
unnamed: IC1.4 (AIN3), R15.2
unnamed: R16.1, X4.1
unnamed: R17.1, X3.1
unnamed: IC1.5 (AIN2), R14.2
unnamed: IC1.7 (AIN0), R12.2
unnamed: IC1.6 (AIN1), R13.2
RESET: R3.2, X1.26
SCLK: R7.2, X1.21
START: R2.2, X1.25
VCC: C1.1, C2.1, C4.1, IC1.15 (IOVDD), IC1.16 (DVDD), IC1.26 (AVDD), R10.2, X1.1

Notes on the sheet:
3V GND VBAT PC13 PC14 PC15 PF0 PF1 GND NRST PC0 PC1 PC2 PC3 PA0 PA1 PA2 PA3 PF4 PF5 PA4 PA5 PA6 PA7 PC4 PC5 PB0 PB1 PB2 PB10 PB11 PB1 GND

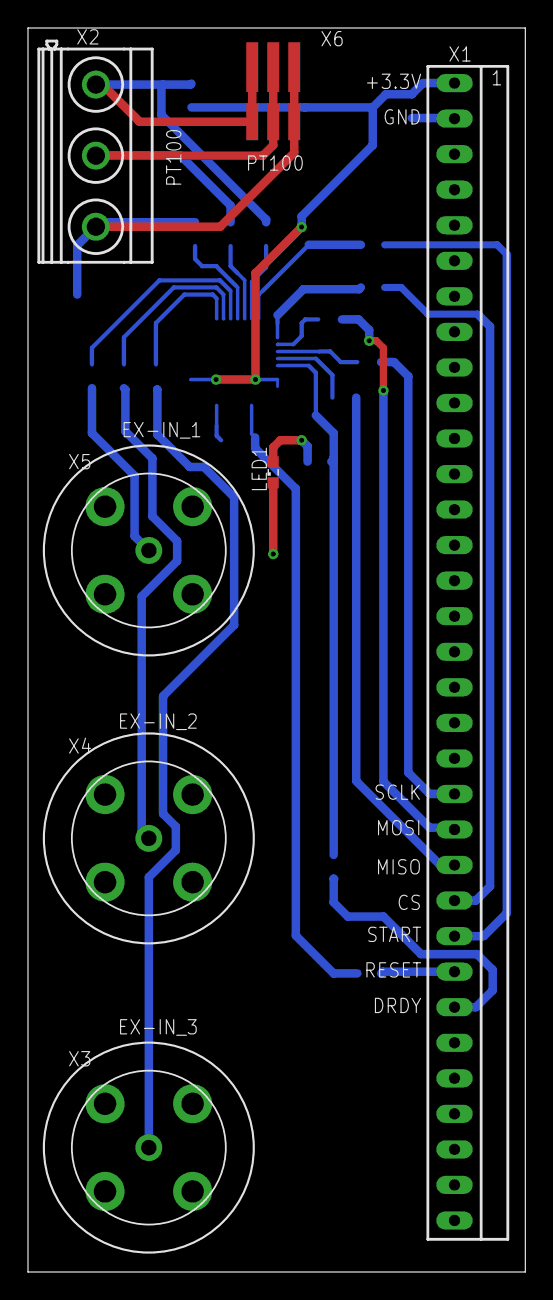
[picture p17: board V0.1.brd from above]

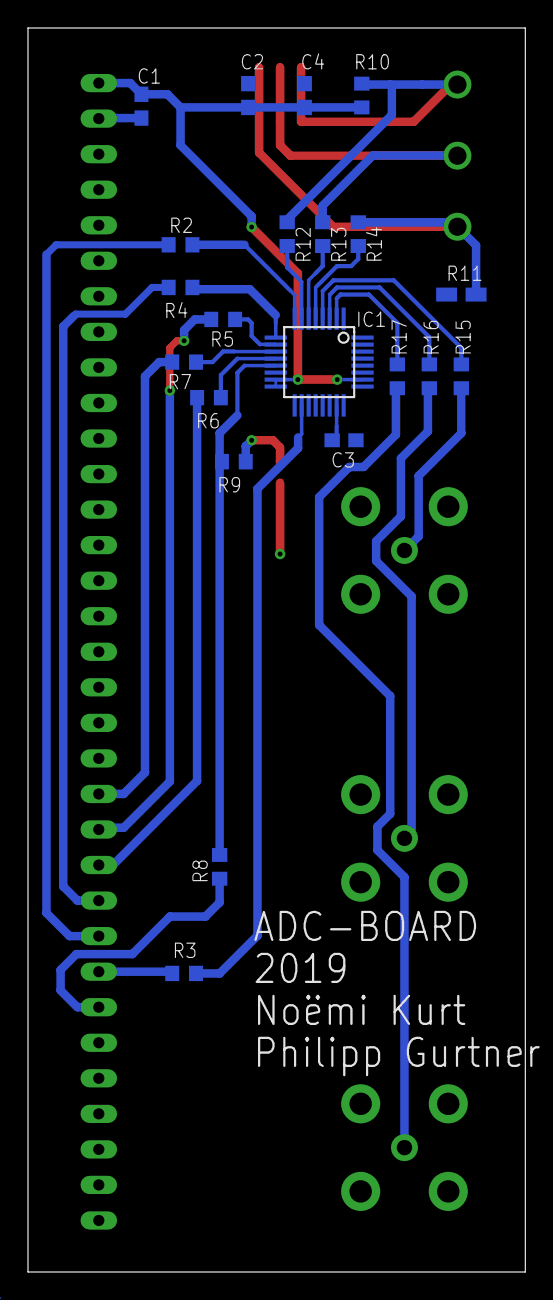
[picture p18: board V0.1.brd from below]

Board: 2 copper layers, 35.5 x 88.9 mm, 28 parts (21 on the bottom side), 30 nets.

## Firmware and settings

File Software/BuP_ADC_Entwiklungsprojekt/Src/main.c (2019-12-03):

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

/* Includes ------------------------------------------------------------------*/
#include "main.h"
#include "spi.h"
#include "gpio.h"

/* USER CODE BEGIN Includes */
#include <math.h>
#include "ADS1204S0x.h"

/* USER CODE END Includes */

/* USER CODE BEGIN PD */

#define fullscale_voltage 2.5		// fullscale_voltage in Volt
#define bitresulution2 8388608		// 2^24 /2 --> Fullscale positiv


/* USER CODE END PD */


/* USER CODE BEGIN PV */

float f_measuredtemperature;		// Global variable for temperature
uint8_t ADCmeasuremenReady=0;		// Flag for measurement
float f_Channel3Measure;			// Global variable for extern input 3

uint8_t au8_registers[REGISTER_COUNT];	// Storrage for all registers (for later uses)



// Enum for statemachine temperaturemeasure
typedef enum {
	DISABLED,
	READY,			// Ready to measure
	NEWMEASURE,		// Data are completly read
	NEWTEMP,		// Data are calculated to temp
	MEASURE			// busy
}t_temperaturstate;


t_temperaturstate tempmeasurementstate = READY;	// define state


// Struct for measurement constants (depending of hardware)
typedef struct {
	float A 	;
	float B 	;
	float C 	;
	float alpha ;
	float R0 	;
	float R_11  ;		// Resistor 11 on ADCBoard (for current calculations )
}t_measurement_constants;


// Define PT100 depends on the used hardware
t_measurement_constants pt100 = {
		3.9083e-3,
		-5.775e-7,
		-4.183e-12,
		 3.85e-3,
		 100,
		 2200			//todo widerstand ist 2 ohm zu hoch --> Nullpunktabgleichen automatisieren :)
};




/* USER CODE END PV */

void SystemClock_Config(void);
/* USER CODE BEGIN PFP */


uint32_t ADCinit(void);

// ADC read registers
uint8_t ADCreadRegs(uint8_t u8_startadress, uint8_t u8_length, uint8_t *pu8_rxdata); 	// Read multiple registers
uint8_t ADCregread(uint8_t startadress);									// Read single register

// ADC write registers
uint8_t ADCwriteRegs(uint8_t startadress, uint8_t length, uint8_t *data);	// Write multiple registers
void ADCregwrite(uint8_t startadress, uint8_t data);						// Write single register


// ADC Commands
void ADCsendCommand(uint8_t op_code);
void ADCstart(void);						// Write START command


uint8_t setADCsigleChannel(uint8_t u8_channel);

// Calculations for temperature
float calctemperature(float Rtemp, t_measurement_constants tempresistor);				// Calculate Tempeature out of Rtemp
float calc_R_temperature(uint32_t *pu32_rawdata, t_measurement_constants tempresistor);	// Calculates Rtemp
float calcAnalogvoltage(uint32_t u32_measurement);										// Calculates analog voltage from input

// Data read funcions
float read_temperature(void);
uint32_t readsingleADCChannel(uint8_t u8_channel);			// Set Channel to required channel, delay until channel is stable, measure...
uint32_t ADRreadInput(uint8_t mode);					// Read data from ADC, mode 0= Command, 1= ISR (DRDY must be high)





/* USER CODE END PFP */

/**
  * @brief  The application entry point.
  * @retval int
  */
int main(void)
{
  

  /* MCU Configuration--------------------------------------------------------*/

  /* Reset of all peripherals, Initializes the Flash interface and the Systick. */
  HAL_Init();

  /* Configure the system clock */
  SystemClock_Config();

  /* Initialize all configured peripherals */
  MX_GPIO_Init();
  MX_SPI1_Init();
  /* USER CODE BEGIN 2 */

  ADCinit();
  /* USER CODE END 2 */

  /* Infinite loop */
  /* USER CODE BEGIN WHILE */

  if(tempmeasurementstate==READY)
  {
	  read_temperature();

  }//tempmeasurementstate;// = ready;

  while (1)
  {
	  /* ToDo
	   * - Berechnungen Widerstand & Temperatur		--> JUHU
	   * - Spannungen von Extern Auslesen			--> JUHU
	   * - ISR zum Auslesen							--> JUHU
	   * - Temperaturmessung ausprobieren			--> JUHU
	   * - Temperaturmesseung kallibrieren			-->
	   */

	  //HAL_GPIO_TogglePin(LD3_GPIO_Port, LD3_Pin);


	 /* for(uint8_t i=0; i<=4; i++)
	  {
		  read_temperature();
	  }

	  if(tempmeasurementstate == NEWTEMP)
	  {
		  f_measuredtemperature = read_temperature();
		  tempmeasurementstate = READY;

	  }
*/

	  f_Channel3Measure=calcAnalogvoltage( readsingleADCChannel(3));


    /* USER CODE END WHILE */

    /* USER CODE BEGIN 3 */
  }
  /* USER CODE END 3 */
}

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
/* USER CODE BEGIN 4 */


/* Diese Funktion wird bei einem DRDY Interrupt automatisch ausgeführt
 * Daten sind bereit und können ausgelesen werden.
 */
void ADC_DRDY_InputHandler(void)
{
	// HAL_GPIO_TogglePin(LD3_GPIO_Port, LD3_Pin);
	 ADCmeasuremenReady=1;
}


uint32_t ADCinit(void)
{
	HAL_Delay(3);												// minimum delay of 2.2 ms to allow power supplies to settle and power-up reset to complete
	HAL_GPIO_WritePin(ADC_RESET_GPIO_Port,ADC_RESET_Pin,1); 	// Set reset
	HAL_GPIO_WritePin(ADC_CS_GPIO_Port,ADC_CS_Pin,1);			//
	HAL_GPIO_WritePin(ADC_START_GPIO_Port, ADC_START_Pin,0);	// Start by command (Start pin LOW)
	HAL_Delay(10);

	while(ADCregread(STATUS_REG_ADDR) & ADS_RDY)				// Ready bit überprüfen  //todo ist bisschen hart wenn immer in dieser while
	{
		HAL_Delay(5);
	}
	ADCregwrite(STATUS_REG_ADDR, ADCregread(STATUS_REG_ADDR)&~ADS_FL_POR); // Clear FL POR Flag (Redback,...)


	ADCsendCommand(WAKE_COMMAND);		// Sollte nicht sein, jedoch zur sicherheit

	//todo

	//Read all Registers to simplify config
	ADCreadRegs(ID_REG_ADDR,REGISTER_COUNT, au8_registers);


	//Set Mode to single conversation opearation (Always use ADCstart() )
	//au8_registers[DATARATE_REG_ADDR] &= ADS_CONVMODE_SS;

	au8_registers[INPMUX_REG_ADDR]	|= (ADS_P_AIN4 | ADS_N_AINCOM); // // Select INPUT (INPMUX- Register): Setzen der Eingänge
	au8_registers[REF_REG_ADDR]		= (ADS_REFINT_ON_ALWAYS+ADS_REFSEL_INT); // Set Internal voltage Reference (2.5V Max inputvoltage = 2.5V)

	ADCwriteRegs(ID_REG_ADDR,REGISTER_COUNT, au8_registers); 	// write all registers



	//ADCregwrite(PGA_REG_ADDR, ADS_PGA_ENABLED);
	//ADCsendCommand(STOP_COMMAND);
	ADCsendCommand(START_COMMAND);

	ADCstart();
	//HAL_GPIO_WritePin(ADC_START_GPIO_Port, ADC_START_Pin,1);	// Start by Pin

	return 0;
}

/* Schreibt ein Register des ADCs
 * @param	startadress 	-> Zu schreibendes Register
 * @param	data			-> Daten für in das Register
 */
void ADCregwrite(uint8_t startadress, uint8_t data)
{
	uint8_t txdata[1] = {data};
	ADCwriteRegs(startadress, 1, txdata);
}

/* Liest ein Register des ADCs
 * @param	startadress	-> zu lesendes Register
 * @resp	Gelesenes Register
 */
uint8_t ADCregread(uint8_t startadress)
{
	uint8_t rxdata[1] = {0};
	ADCreadRegs(startadress, 1, rxdata);
	return rxdata[0];
}

/* Sendet ADC Komando Start (steuerung über Command, Start-PIN = LOW)
 */
void ADCstart(void)
{
	ADCmeasuremenReady=0;
	//ADCsendCommand(START_COMMAND);
}

/* Schreibt mehrere, aufeinanderfolgende Register des ADCs
 * @param	u8_startadress	-> Erstes zu schreibendes Register
 * @param	u8_length		-> Anzahl zu schreibende 8Bit Register
 * @param 	pu8_data		-> Pointer auf Array mit den Daten
 * @resp	erfolgreich =1, sonst 0
 */
uint8_t ADCwriteRegs(uint8_t u8_startadress, uint8_t u8_length, uint8_t *pu8_data)
{
	/*	Protokollaufbau:
	 * 	0b010r'rrrr		Startadress | 0x40 for WriteRegister
	 * 	length -1		0 = 1Byte, 1= 2Byte
	 * 	Data(...)
	 */

	// checks maximal length
	if(u8_length==0 && u8_length > REGISTER_COUNT)	// sonst werden keine Daten gesendet, Max register, 0 ist auch ein register! deshalb >=
	{	
		return 0;
	}
	
	// erstellen eines Array für das senden der Daten
	uint8_t txdata[u8_length+2];
	txdata[0]= u8_startadress | 0x40; 	// set write command
	txdata[1]= u8_length -1; 	// 0x00 is 1 byte
	
	for(uint8_t i=0; i<u8_length; i++)	// Dateiinhalt in txdata plazieren
	{
		txdata[i+2]= *(pu8_data+i);
	}
	
	

	HAL_GPIO_WritePin(ADC_CS_GPIO_Port, ADC_CS_Pin,0);
	HAL_Delay(CHIP_SELECT_WAIT_TIME);

	HAL_SPI_Transmit(&hspi1,txdata,u8_length+2,10);			// +2 for startadress and length, length is only datacount
	
	HAL_Delay(CHIP_SELECT_WAIT_TIME);
	HAL_GPIO_WritePin(ADC_CS_GPIO_Port,ADC_CS_Pin,1);

	return 1;
}

/* Liest mehrere, aufeinanderfolgende Register des ADCs
 * @param	u8_startadress	-> Erstes zu lesendes Register
 * @param	u8_length		-> Anzahl zu lesende 8Bit Register
 * @param 	pu8_rxdata		-> Pointer auf Array mit den Daten
 * @resp	erfolgreich =1, sonst 0	//todo
 */
uint8_t ADCreadRegs(uint8_t u8_startadress, uint8_t u8_length, uint8_t *pu8_rxdata) 	// Speichert rückgabe in rxdata
{
	/*	Protokollaufbau:
	 * 	Senden des Befehles:
	 * 		0b001r'rrrr		Startadress | 0x20 for ReadRegister
	 * 		length -1		0 = 1Byte, 1= 2Byte
	 * 	Lesen der Daten
	 * 	Data(...)
	 */

	// checks maximal length
	if(u8_length==0 && u8_length > REGISTER_COUNT)	// sonst werden keine Daten gesendet, Max register, 0 ist auch ein register! deshalb >=
	{
		return 0;
	}

	uint8_t txdata[2] = {u8_startadress |0x20 , u8_length-1};	// create array for spi transmit (to get a response from ADC)
	
	HAL_GPIO_WritePin(ADC_CS_GPIO_Port, ADC_CS_Pin,0);
	HAL_Delay(CHIP_SELECT_WAIT_TIME);

	HAL_SPI_Transmit(&hspi1,txdata, 2, 10);			//Transmit TX Data (2 Bytes)
	HAL_SPI_Receive(&hspi1, pu8_rxdata, u8_length, 50);		//todo realy +1?

	HAL_Delay(CHIP_SELECT_WAIT_TIME);
	HAL_GPIO_WritePin(ADC_CS_GPIO_Port,ADC_CS_Pin,1);
}

/*	Senden eines Befehls für den ADC
 * 	@param	u8_opcode	-> befehl aus ADS1204S0x.h
 */
void ADCsendCommand(uint8_t u8_opcode)
{
	HAL_GPIO_WritePin(ADC_CS_GPIO_Port, ADC_CS_Pin,0);
	HAL_Delay(CHIP_SELECT_WAIT_TIME);

	uint8_t txbuf[1]= {u8_opcode};				//Start Convertion via Command
	HAL_SPI_Transmit(&hspi1,txbuf,1,10);

	HAL_Delay(CHIP_SELECT_WAIT_TIME);
	HAL_GPIO_WritePin(ADC_CS_GPIO_Port,ADC_CS_Pin,1);
	
}

/*	Read positive ADC Input, as negative is AINCOM set
 * 	Die Funktion kann in der ISR von DRDY ausgeführt werden (mode=0), oder immer (mode=1)
 * 	@param mode =1 -> Read with command , mode = 0 -> DRDY is high !
 * 	@return u32_result
 */
uint32_t ADRreadInput(uint8_t mode) 	// 0=DRDY high, 1=Command
{
		uint8_t rxbuf[3]={1,1,1};
		uint32_t u32_result=0;
		uint8_t dStatus[1];
		uint8_t dCRC[1];


		if (mode == 1) // Read by Command
		{
			ADCsendCommand(RDATA_COMMAND);	//RDATA => Read Data
		}

		HAL_GPIO_WritePin(ADC_CS_GPIO_Port, ADC_CS_Pin,0);
		HAL_Delay(CHIP_SELECT_WAIT_TIME);

		//todo

		// if the Status byte is set - grab it
		if( (au8_registers[SYS_REG_ADDR] & ADS_SENDSTATUS_ENABLE) )
		{
			HAL_SPI_Receive(&hspi1, dStatus,1,10);
		}


		HAL_SPI_Receive(&hspi1,rxbuf,3,10); //Read Datarate Register --> Ohne CRC und Status

		// is CRC enabled?
		if( (au8_registers[SYS_REG_ADDR] & ADS_CRC_ENABLE) )
		{
			HAL_SPI_Receive(&hspi1, dCRC,1,10);

			//todo calc CRC
		}


		HAL_Delay(CHIP_SELECT_WAIT_TIME);
		HAL_GPIO_WritePin(ADC_CS_GPIO_Port,ADC_CS_Pin,1);

		u32_result = rxbuf[0];
		u32_result = (u32_result<<8) + rxbuf[1];
		u32_result = (u32_result<<8) + rxbuf[2];

		return u32_result;
	
}

/*	Setzen eines Inputchannels des ADC (AIN Neg = AINCOM)
 * 	Kanal wird zuerst gesetzt, dann wird gewartet !!
 * 	@param u8_channel 	-> AIN0... AIN5 (ADS124S06), AIN0...AIN11 (ASD124S08)
 * 	@ return  -> success =1
 */
uint8_t setADCsigleChannel(uint8_t u8_channel)
{
	if (au8_registers[ID_REG_ADDR] & ADS_124S06 && u8_channel > (ADS_P_AIN5 >> 4) )	// DS124S06 has only 6 channels (AIN5 is max)
	{
		return 0;
	}
	else if(u8_channel > (ADS_P_AIN11 >> 4) )						// DS124S08 has 12 channels (AIN11 is max)
	{
		return 0;
	}

	else
	{
		ADCregwrite(INPMUX_REG_ADDR,(u8_channel<<4 | ADS_N_AINCOM));
		HAL_Delay(7); 		// Delay until Input is stable (Datasheet p.36, Table 10. Internal Reference Settling Time)
		return 1;
	}
}

/*	Liest einzelnen ADCKanal aus
 * 	@param 	u8_channel -> zu lesender Kanal
 * 	@resp 	-> ADC output
 */
uint32_t readsingleADCChannel(uint8_t u8_channel)
{
	if(setADCsigleChannel(u8_channel))
	{

		ADCstart();
		while(ADCmeasuremenReady!=1);
		return ADRreadInput(1);


	}
	else
	{
		return 0;
	}

}



float read_temperature(void)		//need be called in a while. Flag newtemperatureavaliable is set if set and must be cleared manualy !
{
	static uint32_t au32_rawdata[3];
	static uint8_t u8_rawcounter;
	static float temperature;

	switch(tempmeasurementstate)
	{
		case MEASURE: 		// ISR CALL
			setADCsigleChannel(u8_rawcounter);
			ADCstart();
			while(ADCmeasuremenReady!=1);
			au32_rawdata[u8_rawcounter]= ADRreadInput(1); 	// Read (DRDY is high)
			u8_rawcounter ++;
			if(u8_rawcounter >= 3)
			{
				tempmeasurementstate = NEWMEASURE;
			}

			return u8_rawcounter;
			break;

		case READY:
			u8_rawcounter=0;
			tempmeasurementstate=MEASURE;

			break;

		// Both response are temperature
		case NEWMEASURE:
			u8_rawcounter=0;
			tempmeasurementstate = NEWTEMP;
			temperature = calctemperature( calc_R_temperature(au32_rawdata, pt100), pt100 );
		case NEWTEMP:
			return temperature;

		default:
			return 0;
	}
	return 0;
}

float calc_R_temperature(uint32_t *pu32_rawdata, t_measurement_constants tempresistor)		// Berechnung R_temp
{
	// Berechnung: Upt100= ADC0-2xADC1 + ADC2
	uint32_t u32_result_ADCsteps=  	pu32_rawdata[0] + pu32_rawdata[2] - 2*(pu32_rawdata[1]);

	// Steps to voltage
	float u32_result_ADCvoltage = 	(float) (fullscale_voltage * u32_result_ADCsteps / bitresulution2 );		// bitresolution2 for the positive spectrum

	//  R= U/I = U / ( UR_I / R_I ) =  U * R_I / UR_I
	float Voltage_R_11 =  (float) (fullscale_voltage * pu32_rawdata[2] / bitresulution2);

	return (u32_result_ADCvoltage * tempresistor.R_11 / Voltage_R_11 );
}

float calctemperature(float Rtemp, t_measurement_constants tempresistor)
{
	if(Rtemp>=100)		// ToDo Temperatur >= 0°C
	{
		/* For Calculate the temperature from the Resistance in positve the Callendar-Van Dusen equation is used.
		 * https://en.wikipedia.org/wiki/Resistance_thermometer
		 * 	T= -A + sqrt(A^2 - 4*B *(1- (Rtemp/R0) )) / 2*B
		 */

		return (-tempresistor.A + sqrt((tempresistor.A * tempresistor.A) - 4*tempresistor.B*(1-(Rtemp/tempresistor.R0))))	/(2*tempresistor.B);
	}
	else
	{
		/*
		 * Negative Temperature
		 * For easy calculating, the same formula is used in negative temperature.
		 * He isn't correct because C isn't 0 as in the positive temperature
		 * In this case we get a measurement error
		 * todo for future improuvement a new calculation
		 */

		return (-tempresistor.A + sqrt((tempresistor.A * tempresistor.A) - 4*tempresistor.B*(1-(Rtemp/tempresistor.R0))))	/(2*tempresistor.B);
	}

}



float calcAnalogvoltage(uint32_t u32_measurement)
{
	return fullscale_voltage * u32_measurement / bitresulution2;
}


/* USER CODE END 4 */
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


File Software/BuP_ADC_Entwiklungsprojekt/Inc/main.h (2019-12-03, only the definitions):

#define ADC_CS_Pin GPIO_PIN_5
#define ADC_CS_GPIO_Port GPIOF
#define ADC_START_Pin GPIO_PIN_4
#define ADC_START_GPIO_Port GPIOC
#define ADC_RESET_Pin GPIO_PIN_5
#define ADC_RESET_GPIO_Port GPIOC
#define ADC_DRDY_Pin GPIO_PIN_0
#define ADC_DRDY_GPIO_Port GPIOB
#define ADC_DRDY_EXTI_IRQn EXTI0_1_IRQn
#define LD4_Pin GPIO_PIN_8
#define LD4_GPIO_Port GPIOC
#define LD3_Pin GPIO_PIN_9
#define LD3_GPIO_Port GPIOC
#define SWDIO_Pin GPIO_PIN_13
#define SWDIO_GPIO_Port GPIOA
#define SWCLK_Pin GPIO_PIN_14
#define SWCLK_GPIO_Port GPIOA

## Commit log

2019-04-03 add EagleFiles
    [V0.1.sch]
2019-06-06 Stand der Abgabe
    [Berechnungen_ADC.xlsx, V0.1.brd, V0.1.sch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]
2019-08-29 add Programmierung & Verbesserung
    [V0.2.brd, V0.2.sch]
2019-09-19 Software Start & Aufgeräumt
    [Berechnungen_ADC.xlsx, V0.2.brd, V0.2.sch]
2019-12-04 Finish V02
    New order of hardwarefiles
    [BOM.xlsx, V0.1.brd, V0.1.sch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]
2019-12-10 Schemaänderung; BNC-Abschwächer
    [V0.2.brd, V0.2.sch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]

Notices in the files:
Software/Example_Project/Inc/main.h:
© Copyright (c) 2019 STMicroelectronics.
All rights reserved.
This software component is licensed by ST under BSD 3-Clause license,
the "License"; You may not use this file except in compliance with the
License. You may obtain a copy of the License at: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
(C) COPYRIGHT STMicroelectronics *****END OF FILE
